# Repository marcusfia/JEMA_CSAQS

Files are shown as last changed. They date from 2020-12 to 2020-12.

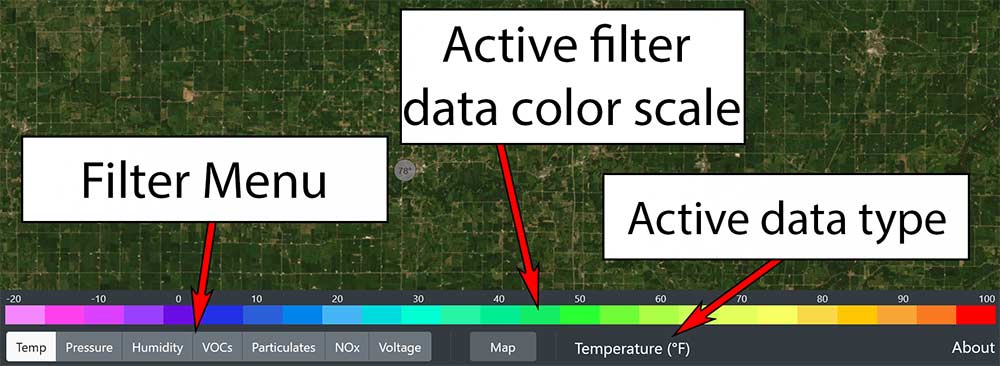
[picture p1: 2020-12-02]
wiki/images/desktop_menu2.jpg

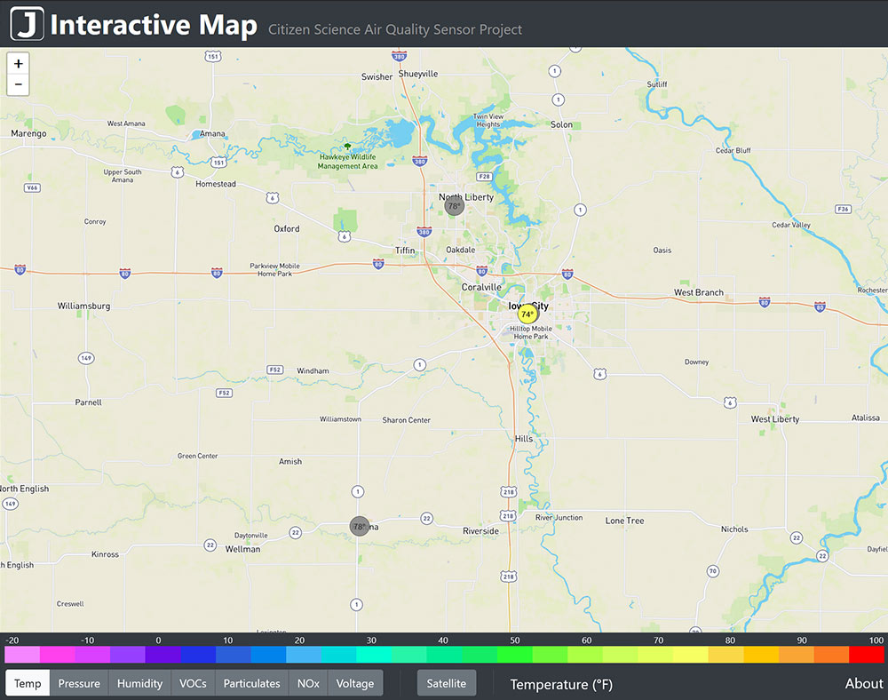
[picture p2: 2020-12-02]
wiki/images/fullmap.jpg

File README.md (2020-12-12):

# **JEMA SD Project - Citizen Science Air Quality Sensor**
Sponsered by Dr. Jun Wang and the University of Iowa ARROMA Lab

This repository contains all source code used for the project.

If you would like to know more about the project software/hardware or access user guides, please visit the project wiki:

## [Project Wiki](https://github.com/marcusfia/JEMA_CSAQS/wiki)

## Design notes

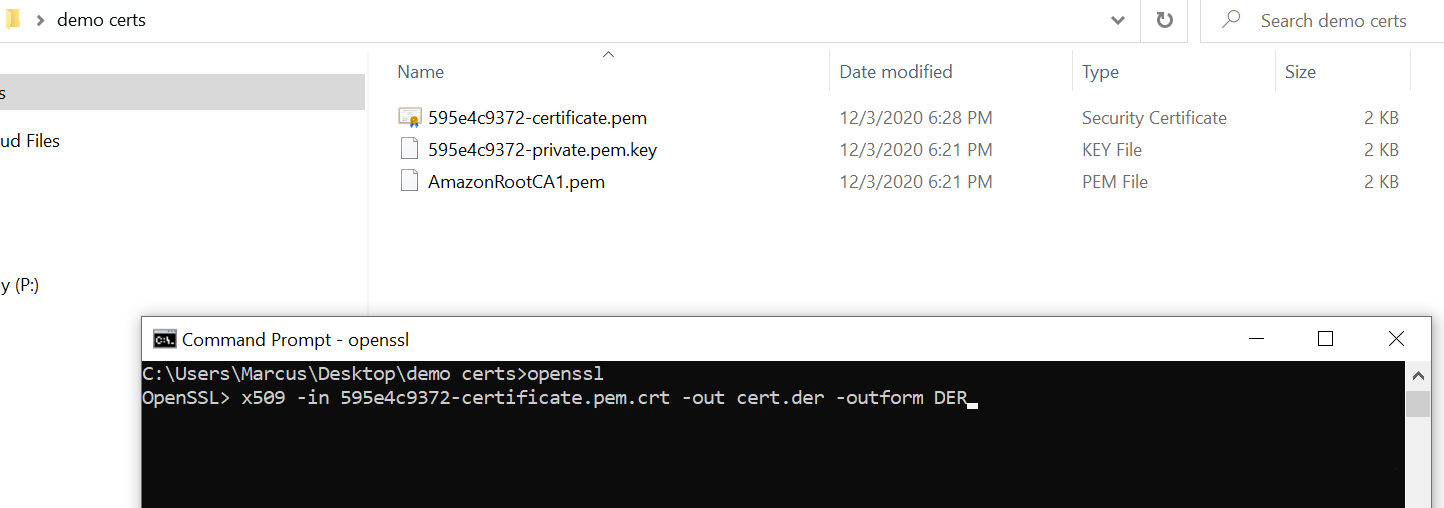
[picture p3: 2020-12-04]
wiki/images/cert_4.png

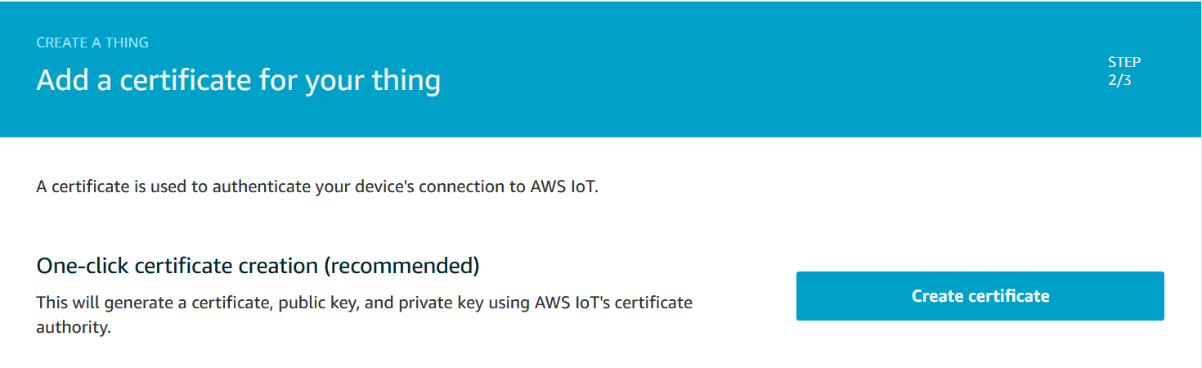
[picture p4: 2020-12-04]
wiki/images/cert_1.png

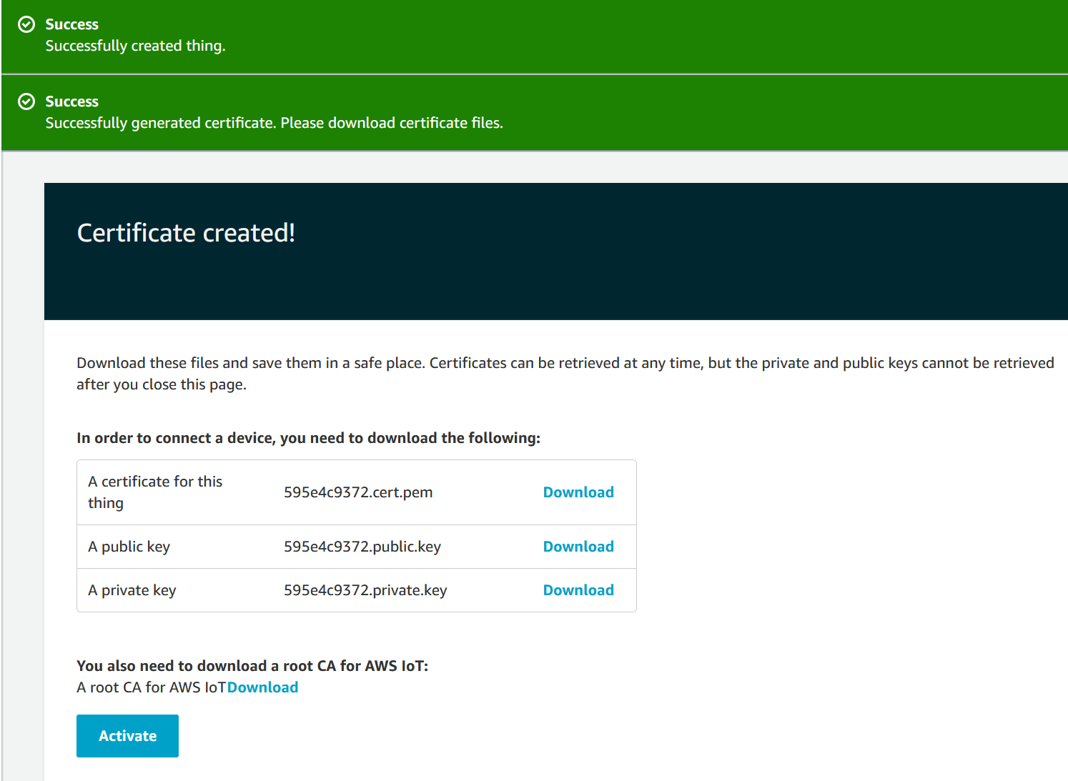
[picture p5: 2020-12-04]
wiki/images/cert_2.png

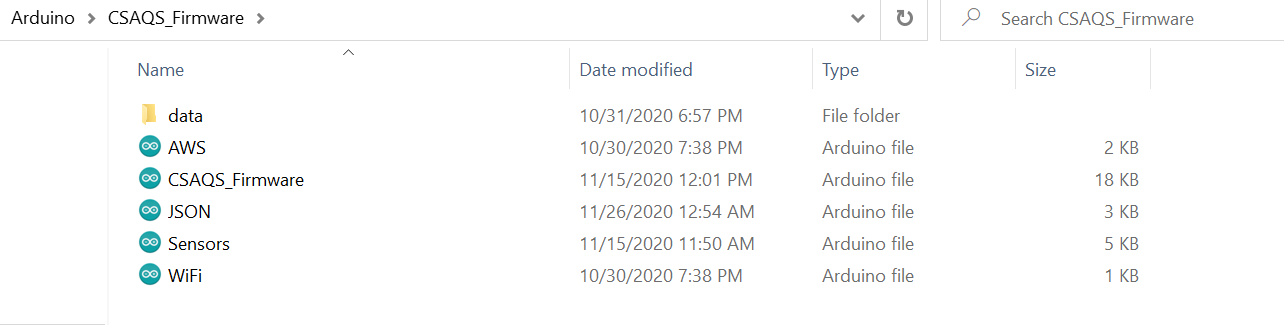
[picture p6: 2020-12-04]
wiki/images/cert_6.png

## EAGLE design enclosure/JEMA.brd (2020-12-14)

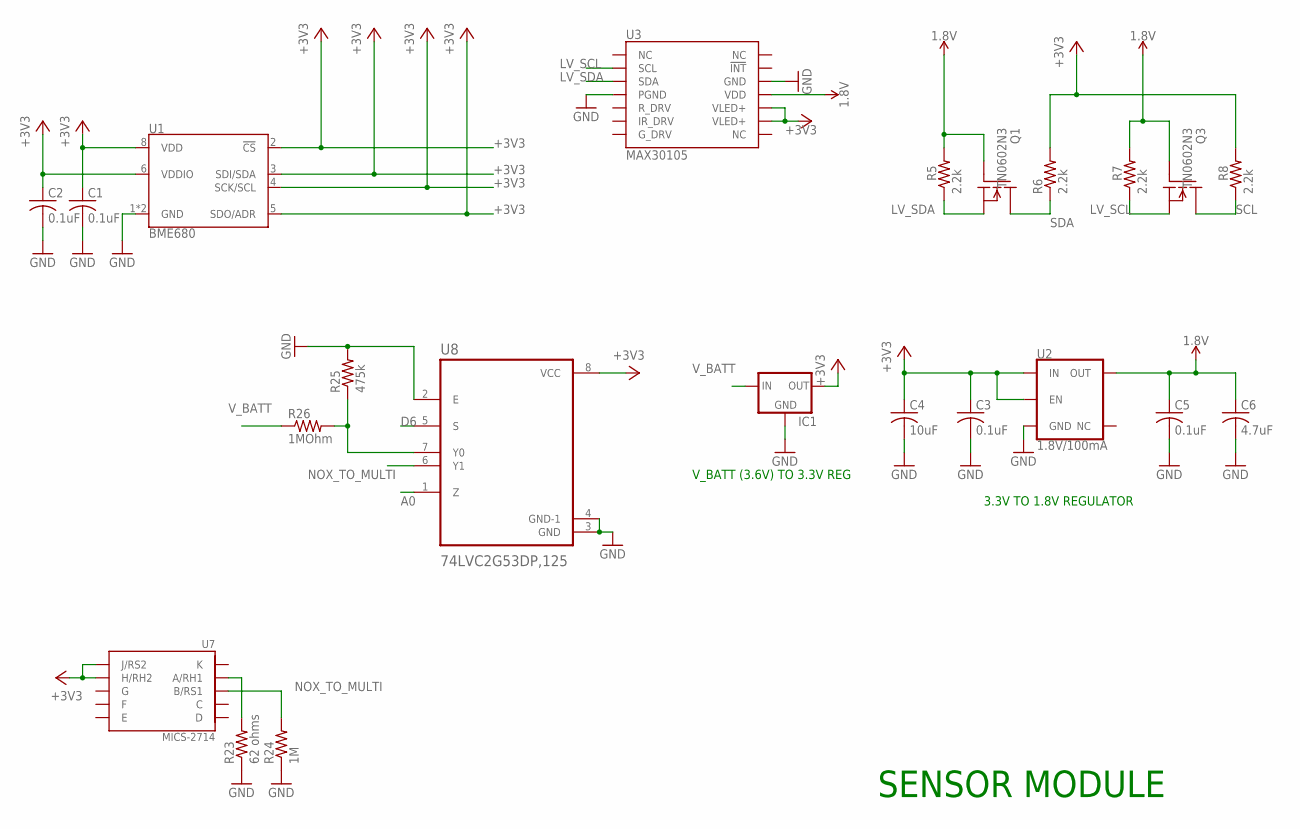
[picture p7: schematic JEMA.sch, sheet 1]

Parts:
C1, C2, C3, C5: 0.1uF; C0805
C4: 10uF; C0805
C6: 4.7uF; C0805
IC1: MCP1700TRI; TO92
Q1, Q3: TN0602N3; TO-92
R5, R6, R7, R8: 2.2k; R0805
R23: 62 ohms; M0805
R24: 1M; M0805
R25: 475k; M0805
R26: 1MOhm; M0805
U1: BME680; LGA3.0X3.0
U2: 1.8V/100mA; SC70
U3: MAX30105; OLGA-14
U7: MICS-2714; MICS-SMD10
U8: 74LVC2G53DP,125; SOP65P490X110-8N

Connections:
1.8V: C5.1, C6.1, Q1.2 (G), Q3.2 (G), R5.2, R7.2, U2.5 (OUT), U3.11 (VDD)
+3V3: C1.1, C2.1, C3.1, C4.1, IC1.3 (OUT), R6.2, R8.2, U1.2 (!CS), U1.3 (SDI/SDA), U1.4 (SCK/SCL), U1.5 (SDO/ADR), U1.6 (VDDIO), U1.8 (VDD), U2.1 (IN), U2.3 (EN), U3.9 (VLED+), U3.10 (VLED+), U7.H (H/RH2), U7.J (J/RS2), U8.8 (VCC); also elsewhere on the board
A0: U8.1 (Z); also elsewhere on the board
D6: U8.5 (S); also elsewhere on the board
GND: C1.2, C2.2, C3.2, C4.2, C5.2, C6.2, IC1.1 (GND), R23.1, R24.1, R25.2, U1.1 (GND), U1.7 (GND), U2.2 (GND), U3.4 (PGND), U3.12 (GND), U8.2 (E), U8.3 (GND), U8.4 (GND-1); also elsewhere on the board
LV_SCL: Q3.1 (S), R7.1, U3.2 (SCL)
LV_SDA: Q1.1 (S), R5.1, U3.3 (SDA)
unnamed: R25.1, R26.2, U8.7 (Y0)
unnamed: R23.2, U7.A (A/RH1)
NOX_TO_MULTI: R24.2, U7.B (B/RS1), U8.6 (Y1)
SCL: Q3.3 (D), R8.1; also elsewhere on the board
SDA: Q1.3 (D), R6.1; also elsewhere on the board
V_BATT: IC1.2 (IN), R26.1; also elsewhere on the board

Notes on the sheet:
V_BATT (3.6V) TO 3.3V REG
3.3V TO 1.8V REGULATOR
SENSOR MODULE

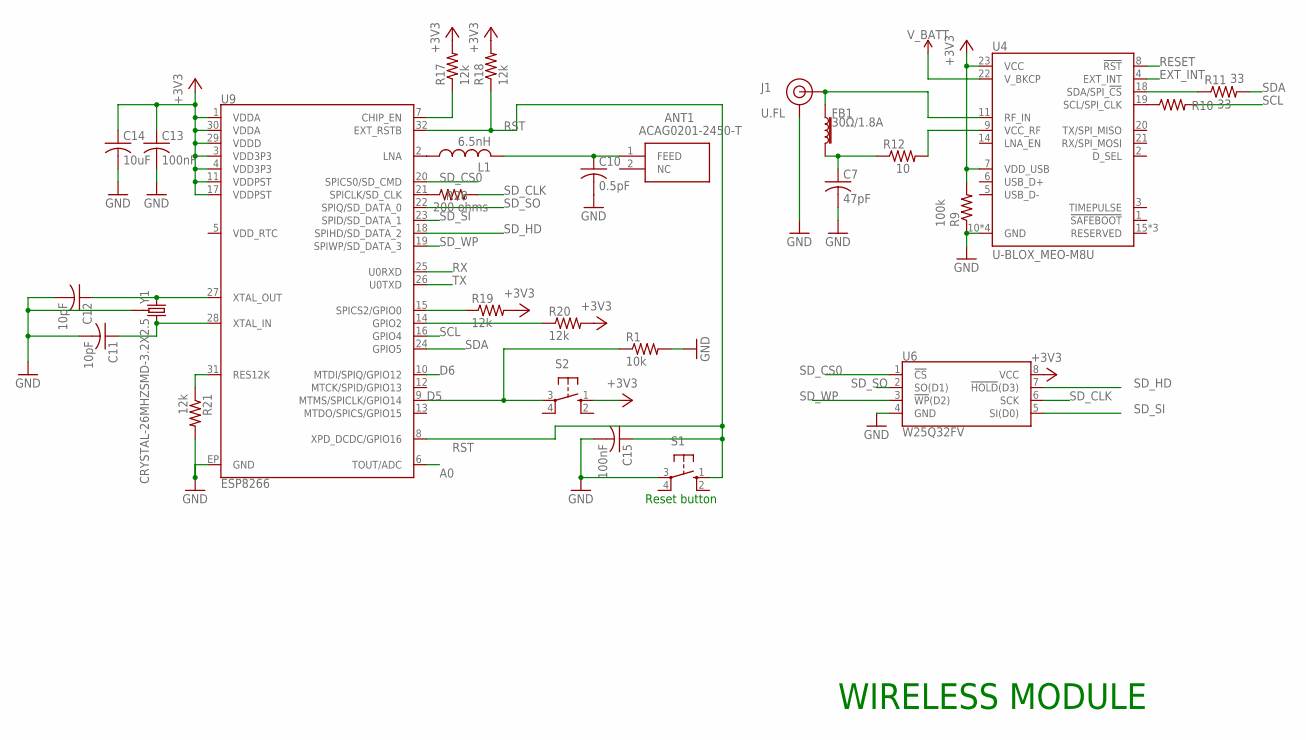
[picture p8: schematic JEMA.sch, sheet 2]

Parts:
ANT1: ACAG0201-2450-T; ANTC2012X70N
C7: 47pF; C0805
C10: 0.5pF; C0805
C11, C12: 10pF; C0805
C13, C15: 100nF; C0805
C14: 10uF; C0805
FB1: 30Ω/1.8A; 0603
J1: U.FL
L1: 6.5nH; L3225M
R1: 10k; R0805
R9: 100k; R0805
R10, R11: 33; R0805
R12: 10; R0805
R17, R18, R19, R20, R21: 12k; M0805
R28: 200 ohms; R0805
S1, S2: 10-XX; B3F-10XX
U4: U-BLOX_MEO-M8U; NEO-M9N/M8T/M8U
U6: W25Q32FV; SOIC-8
U9: ESP8266; QFN32-5X5MM
Y1: CRYSTAL-26MHZSMD-3.2X2.5; CRYSTAL-SMD-3.2X2.5MM

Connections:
+3V3: C13.1, C14.1, R9.2, R17.2, R18.2, R19.2, R20.2, S2.1 (S), U4.7 (VDD_USB), U4.23 (VCC), U6.8 (VCC), U9.1 (VDDA), U9.3 (VDD3P3), U9.4 (VDD3P3), U9.11 (VDDPST), U9.17 (VDDPST), U9.29 (VDDD), U9.30 (VDDA); also elsewhere on the board
A0: U9.6 (TOUT/ADC); also elsewhere on the board
D5: R1.1, S2.3, U9.9 (MTMS/SPICLK/GPIO14)
D6: U9.10 (MTDI/SPIQ/GPIO12); also elsewhere on the board
EXT_INT: U4.4 (EXT_INT)
GND: C7.2, C10.2, C11.2, C12.2, C13.2, C14.2, C15.2, J1.1 (GND), J1.2 (GND), R1.2, R9.1, R21.2, S1.3, U4.10 (GND), U4.12 (GND), U4.13 (GND), U4.24 (GND), U6.4 (GND), U9.EP (GND), Y1.2 (GND), Y1.4 (GND); also elsewhere on the board
unnamed: R10.1, U4.19 (SCL/SPI_CLK)
unnamed: R11.1, U4.18 (SDA/SPI_!CS!)
unnamed: C7.1, FB1.2, R12.1
unnamed: R12.2, U4.9 (VCC_RF)
unnamed: R17.1, U9.7 (CHIP_EN)
unnamed: L1.1, U9.2 (LNA)
unnamed: ANT1.1 (FEED), C10.1, L1.2
unnamed: R19.1, U9.15 (SPICS2/GPIO0)
unnamed: R20.1, U9.14 (GPIO2)
unnamed: R21.1, U9.31 (RES12K)
unnamed: C12.1, U9.27 (XTAL_OUT), Y1.1
unnamed: C11.1, U9.28 (XTAL_IN), Y1.3 (2)
unnamed: FB1.1, J1.FEED (SIGNAL), U4.11 (RF_IN)
unnamed: R28.1, U9.21 (SPICLK/SD_CLK)
RESET: U4.8 (!RST)
RST: C15.1, R18.1, S1.1 (S), U9.8 (XPD_DCDC/GPIO16), U9.32 (EXT_RSTB)
RX: U9.25 (U0RXD)
SCL: R10.2, U9.16 (GPIO4); also elsewhere on the board
SDA: R11.2, U9.24 (GPIO5); also elsewhere on the board
SD_CLK: R28.2, U6.6 (SCK)
SD_CS0: U6.1 (!CS!), U9.20 (SPICS0/SD_CMD)
SD_HD: U6.7 (!HOLD!(D3)), U9.18 (SPIHD/SD_DATA_2)
SD_SI: U6.5 (SI(D0)), U9.23 (SPID/SD_DATA_1)
SD_SO: U6.2 (SO(D1)), U9.22 (SPIQ/SD_DATA_0)
SD_WP: U6.3 (!WP!(D2)), U9.19 (SPIWP/SD_DATA_3)
TX: U9.26 (U0TXD)
V_BATT: U4.22 (V_BKCP); also elsewhere on the board

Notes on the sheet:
Reset button
WIRELESS MODULE

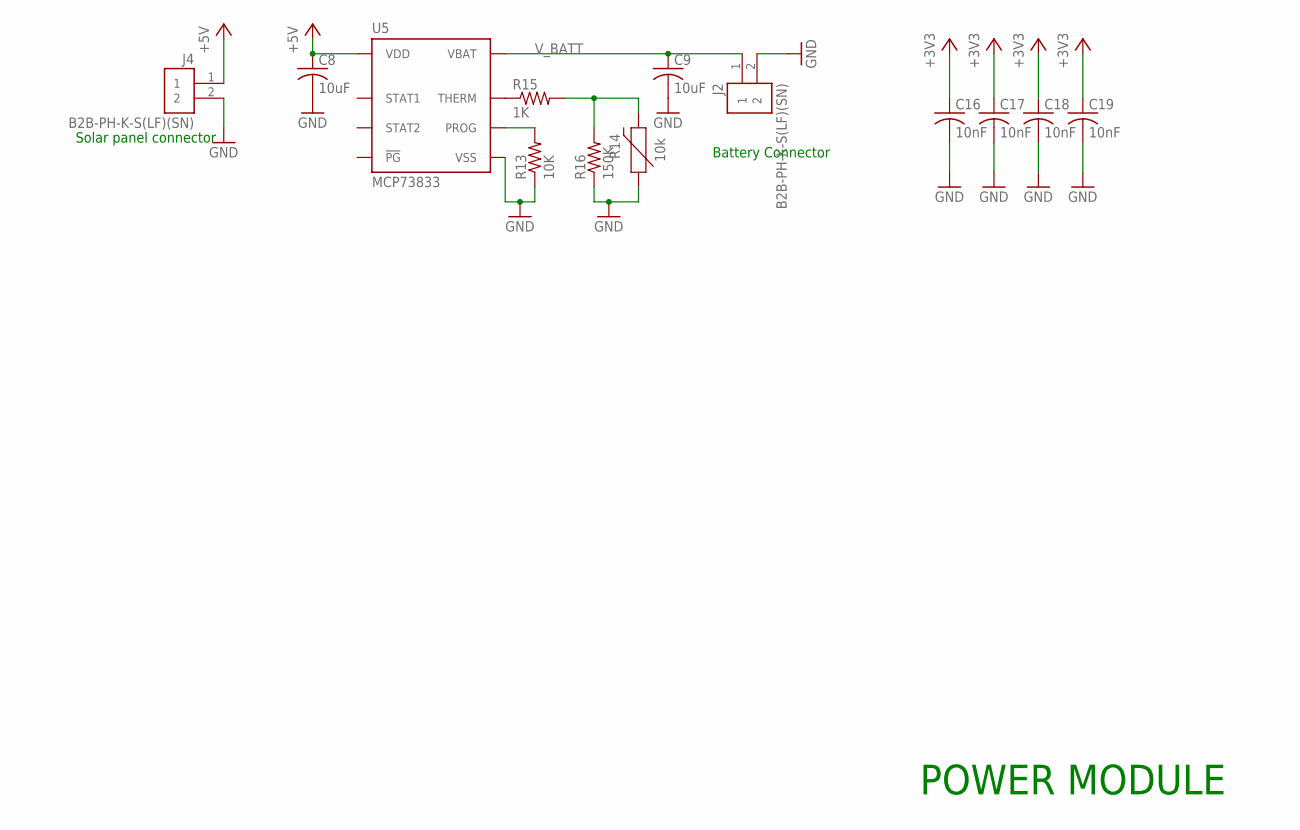
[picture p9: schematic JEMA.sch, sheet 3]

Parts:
C8, C9: 10uF; C0805
C16, C17, C18, C19: 10nF; C0805
J2, J4: B2B-PH-K-S(LF)(SN); JST_B2B-PH-K-S(LF)(SN)
R13: 10K; R0805
R14: 10k; 0603
R15: 1K; R0805
R16: 150K; R0805
U5: MCP73833; DFN-10

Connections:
+3V3: C16.1, C17.1, C18.1, C19.1; also elsewhere on the board
+5V: C8.1, J4.1, U5.P$1 (VDD), U5.P$2 (VDD)
GND: C8.2, C9.2, C16.2, C17.2, C18.2, C19.2, J2.2, J4.2, R13.1, R14.1, R16.1, U5.P$5 (VSS), U5.P$11 (VSS); also elsewhere on the board
unnamed: R13.2, U5.P$6 (PROG)
unnamed: R15.1, U5.P$8 (THERM)
unnamed: R14.2, R15.2, R16.2
V_BATT: C9.1, J2.1, U5.P$9 (VBAT), U5.P$10 (VBAT); also elsewhere on the board

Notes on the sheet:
POWER MODULE
Battery Connector
Solar panel connector

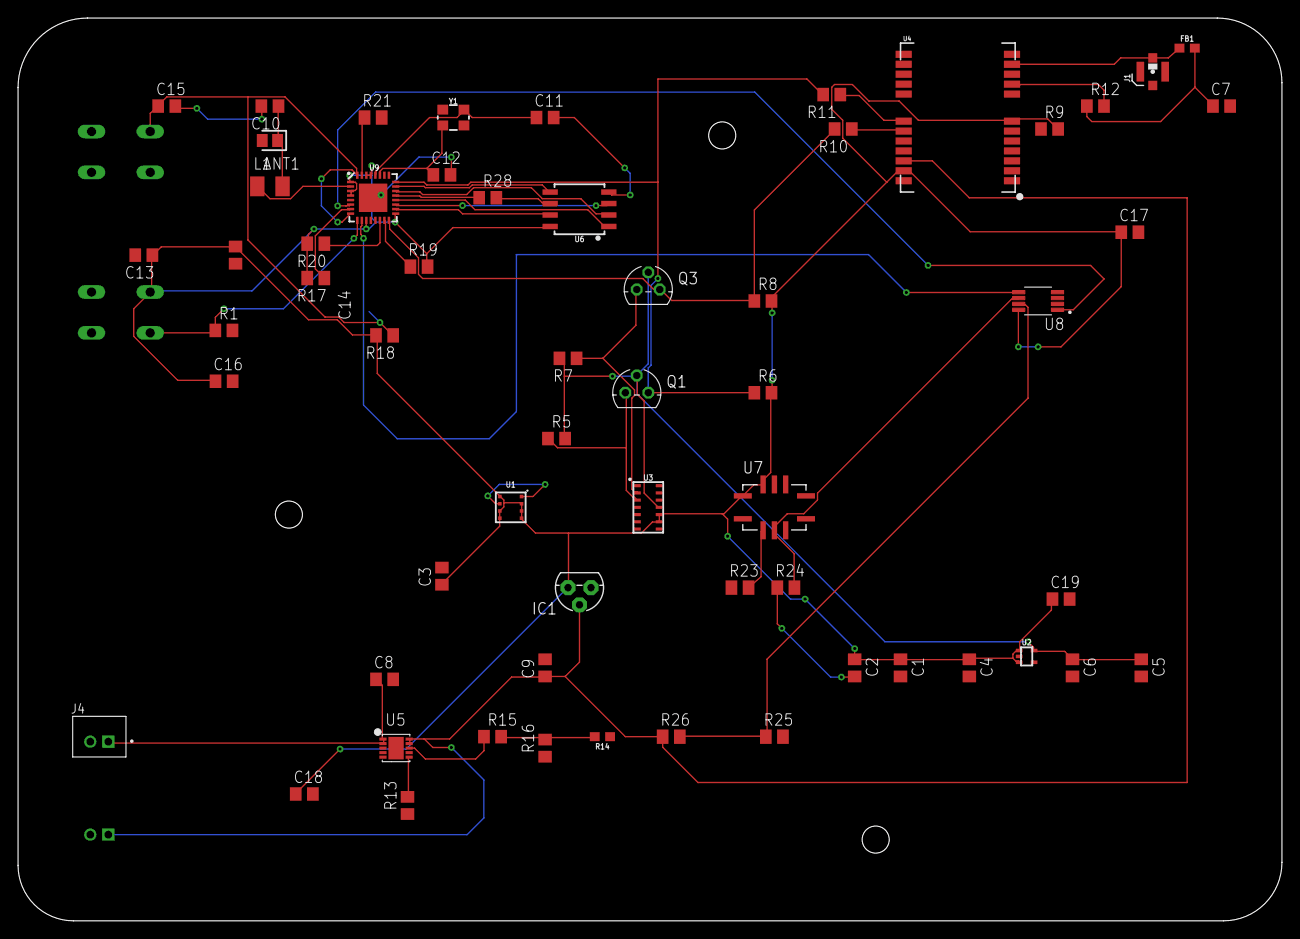
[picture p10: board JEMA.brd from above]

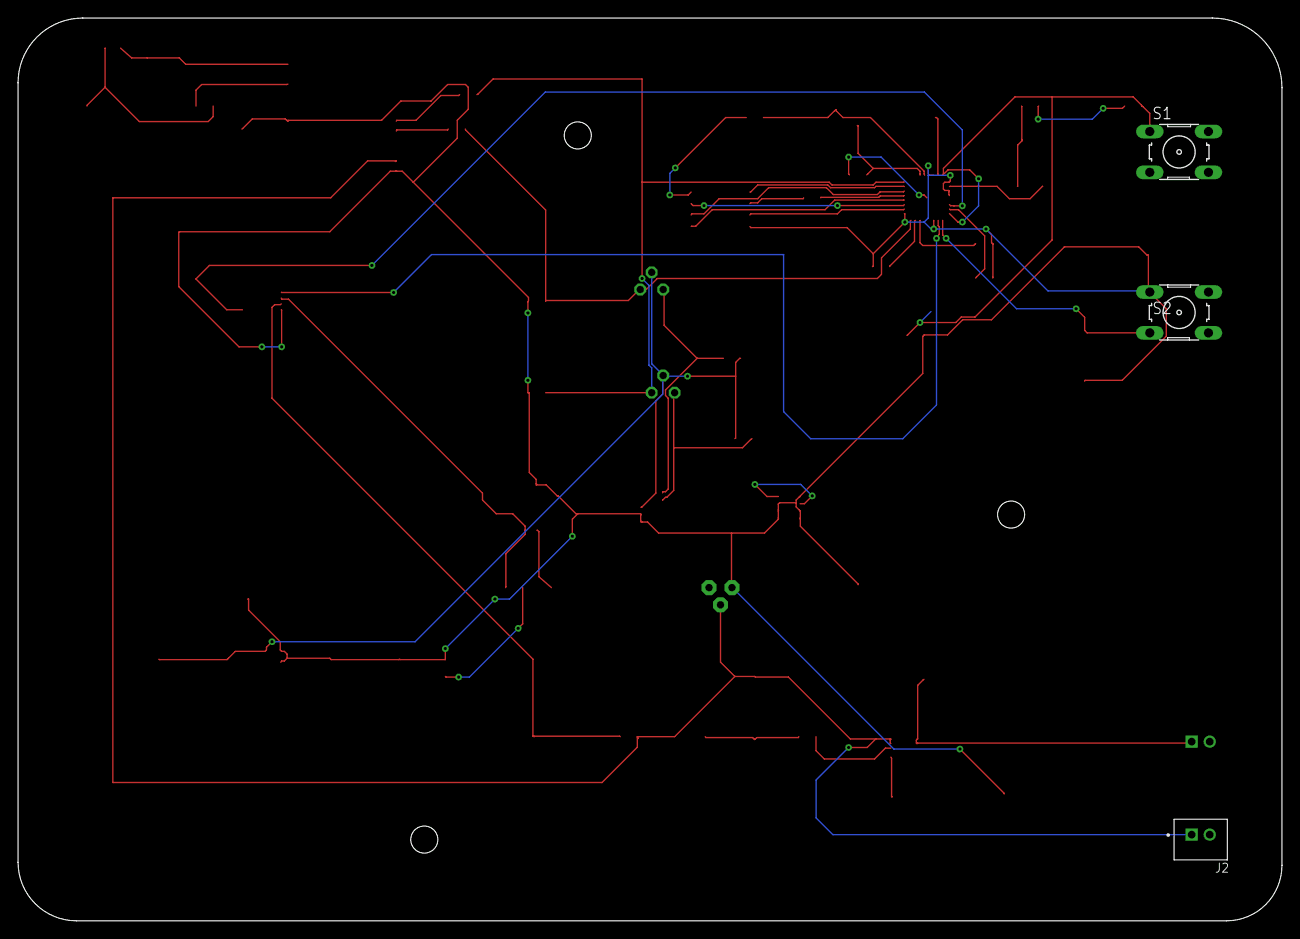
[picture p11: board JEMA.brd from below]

Board: 2 copper layers, 140.0 x 100.0 mm, 63 parts (3 on the bottom side), 39 nets.

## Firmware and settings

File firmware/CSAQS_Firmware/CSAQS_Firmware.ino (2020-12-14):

//////////////////////////////////////////////////////////////////////////////////////////////////////////////////////////////////////
//                             Citizen Science Air Quality Sensor - Device Firmware  (v0.1)
//
//                                                       by
//
//                                                   JEMA Designs
//
//
//                               University of Iowa - Electrical and Computer Engineering
//                                         Senior Design Project - Fall 2020
// 
//
//
//
//                                               in conjunction with -
//
//
//
//
//
//
//                                       Dr. Jun Wang & ARROMA Lab (arroma.uiowa.edu)
//
//   NOTES  ----------------------------------------------------------------------------------------------------------------------
//   9/12/2020 (AW)  - This is a sample note. Start each note with the date, and your initials in paretheses.  Do no remove notes
//   , instead update with a new note, stating that the previous issue is now resolved or changed (reference to the date to make it
//   simple to find what matches to what.  Use multiple lines if needed for a given note, like this one.
//   9/33/2020 (AW)  - This would be the next note......
//   9/04/2020 (AW)  - Added code to read push button to be used for forcing device into Access Point mode. Push button will be a pull
//   -down resistor in order to consume the least amount of power.
//   10/20/2020 (AW) - Contributions by Jarrett for polling of sensors and reading of analog inputs
//   10/20/2020 (AW) - Merged firmware code with Marcus's wifi transmission firmware. Includes MQTT setup, AWS connection & WiFi connection
//   10/21/2020 (AW) - Added code to read & translate NOx sensor
//   10/21/2020 (AW) - Built out deep sleep mode and alpha device firmware --NOTE Deep Sleep not currently active,falls through to main loop
//   10/23/2020 (AW) - Major re-organization of code; usage of Arduino file tabs to separate out code and make more legible
//   10/23/2020 (AW) - Added new debug flag - DEBUG_OUT, for turning on and off the Serial data.  Can be used during normal or debug modes
//   10/23/2020 (AW) - Added enumerations for checking the power supply values, added logic points for dealing with power supply
//   10/24/2020 (AW) - Added changes Marcus made to JSON payload, added Jarrett's SIV code, added Marcus's device ID code
//   10/29/2020 (JH) - Added WifiManager and made it so AP can get a wifi and be resest with a buttonPressed Commented out because it suppresses
//   - the Serial output
//   10/30/2020 (MF) - Updated JSON to not prepend mac address to clientID. This was causing conflicts in API Gateway.
//   10/31/2020 (MF) - Updated TTL in JSON to 30 from 600 to decrease burden on DB and updated delays for loading certs from 1s to 100ms.
//   11/01/2020 (AW) - Fixed battery level calculation.
//   11/09/2020 (AW) - Implemented sleep mode for GPS, cleaned up & re-organized code
//   11/12/2020 (AW) - Implemented sampling protocol for analog input - uses an averaging method, variable re-naming
//   11/22/2020 (AW) - Added check against the fix statue of the GPS.  If no good GPS, wait 5 seconds, try again. Do this up to 10 times, then move on.
//   11/22/2020 (AW) - Added else checks to power supply if block to avoid unneeded checks
//   11/23/2020 (AW) - Adjusted power supply value enumerations based on battery life testing

//////////////////////////////////////////////////////////////////////////////////////////////////////////////////////////////////////
// DEBUG FLAGS    
boolean DEBUG_MODE = false;            // SET DEBUG MODE to TRUE to disable WIFI/AWS/MQTT and Payload Transmit

boolean DEBUG_OUT = true;             //Turns on and off the serial output messages

boolean SENSOR_CAPTURE_MODE = false;  //Uses AWS transmission, but different sampling frequencies and no enabled sleep mode

//////////////////////////////////////////////////////////////////////////////////////////////////////////////////////////////////////
//  Include Headers

#include "FS.h"
#include <ESP8266WiFi.h>
#include <PubSubClient.h>
#include <NTPClient.h>
#include <WiFiUdp.h>
#include <Wire.h>
#include <EEPROM.h>                             //EEPROM storage in Flash used for UBLOX-GPS

#include <WiFiManager.h>                        //https://github.com/tzapu/WiFiManager WiFi Configuration Magic
#include "Zanshin_BME680.h"                     //BME680 by Zanshin

#include "SparkFun_Ublox_Arduino_Library.h"     //u-blox NEO-M8U

#include "heartRate.h"                          //MAX 30105
#include "spo2_algorithm.h"                     //MAX 30105
#include "MAX30105.h"                           //MAX 30105

//////////////////////////////////////////////////////////////////////////////////////////////////////////////////////////////////////
//  Enumerations
enum PowerSupplyState 
{
  PWR_UNKNOWN  = 0,
  BATT_AT_DEAD = 1,
  BATT_AT_10   = 2,
  BATT_AT_50   = 3,
  BATT_AT_75   = 4,
  BATT_AT_MAX  = 5,
  SOLAR_PWR    = 6
};

enum PowerSupplyValues //Correlate the voltage x 100 (e.g. 360 = 3.60 volts x 100)
{
  BATTERY_DEAD = 355,
  BATTERY_10   = 358,
  BATTERY_20   = 366,
  BATTERY_50   = 390,
  BATTERY_75   = 410,
  BATTERY_MAX  = 430
};

enum DeepSleepDuration
{
  DUR_1HR = 3600,
  DUR_5MIN = 300,
  DUR_10MIN = 600,
  DUR_10SEC = 10,
  DUR_30SEC = 30
};
//////////////////////////////////////////////////////////////////////////////////////////////////////////////////////////////////////
//  Hardware Defines

#define UART_SPD    115200         //Serial communication speed setting

// Wemos board pin definitions to ESP8266 definitions
#define D0          16         //Used for deep sleep functions - DO NOT USE
#define D1          5          //SCL for I2C
#define D2          4          //SDA for I2C
#define D3          0          //Used for programming chip
#define D4          2          //Used for programming chip
#define D5          14         //Used for push button
#define D6          12         //Used for multiplexer select
#define D7          13
#define D8          15

//Device specific pin/logic defines
#define MUX_SELECT   12        //Multiplexer Select pin
#define SCL          5         //SCL pin
#define SDA          4         //SDA pin
#define PUSH_BUTTON  14        //Push button input pin
#define PWR_SUPPLY   0         //Logic level for MUX_SELECT to read power supply input from analog read
#define NOX_SENSOR   1         //Logic level for MUX_SELECT to read NOX sensor from analog read

//////////////////////////////////////////////////////////////////////////////////////////////////////////////////////////////////////
//  Objects and Variable

// AWS Credentials
const char* AWS_ENDPOINT  = "a3rqtvxgwfds5w-ats.iot.us-west-2.amazonaws.com";
char* AWS_IOT_CORE_CLIENT_ID = "trappist";
char* AWS_IOT_CORE_PUBLISH_TOPIC = "trappist/pub"; // AWS topic to publish to
const int MQTT_PAYLOAD_SIZE = 512;                 // Max size for buffer for payload
String payload;                                    // Stores the payload information
String db_device_ID;                               // Creates unique ID for queries
char msg[MQTT_PAYLOAD_SIZE];                       // stores msg to publish


//for receving messages IF the device is subscribed to something (not applicable currently)
void callback(char* topic, byte* payload, unsigned int length)
{
  Serial.print("Message arrived [");
  Serial.print(topic);
  Serial.print("] ");
  for (int i = 0; i < length; i++) 
  {
    Serial.print((char)payload[i]);
  }
}


// Instance Objects
WiFiClientSecure espClient;
PubSubClient client(AWS_ENDPOINT, 8883, callback, espClient); 
WiFiUDP ntpUDP;
NTPClient timeClient(ntpUDP, "pool.ntp.org");
BME680_Class BME680;        //BME60 I2C address = 0x77
MAX30105 particleSensor;    //MAX30105 I2C address = 0x57
SFE_UBLOX_GPS ubloxGPSObj;  //GPS I2C address = 0x42
WiFiManager wifiManager;

//BME680 variables
static int32_t temp;
static int32_t humidity;
static int32_t pressure;
static int32_t gas;
String tempStr;
String humidityStr;
String pressureStr;
String gasStr;

//Sensor enabled check declarations
bool gpsEnabled      = false;
bool bme680Enabled   = false;
bool max30105Enabled = false;

//Analog read & power supply variables
float voltage_divider_scalar = 19.936;      // power supply divison coeffecient 
float NOx_voltage_divider_scalar = 3.21056; //coefficient for NOx sensor reading
float ADC_resolution = 1024;                // 10 bit ADC
int read_A0;                                // Pin A0 on ESP8266 used for analog read of power
int currentPowerState;                      // Stores enumeration of current status of power supply
float vcc;
float noxSensorRead;

//MAX30105 variables
String red;  
String green;
String IR;

//u-blox variables
String latitude;
String longitude;
String altitude;
byte SIV;

//Deep Sleep Duration (in seconds)
static int32_t deepSleepDuration;

//////////////////////////////////////////////////////////////////////////////////////////////////////////////////////////////////////
// Setup

void setup()
{
  if(DEBUG_OUT)  //If using our serial output, set it up
  {
    Serial.begin(UART_SPD);
    Serial.setDebugOutput(true);
    delay(1000);
  }
  deepSleepDuration = DUR_5MIN;     //Default sampling rate is set here
  
  // setup pins and multiplexer
  pinMode(MUX_SELECT, OUTPUT);
  pinMode(PUSH_BUTTON, INPUT);
  digitalWrite(MUX_SELECT, PWR_SUPPLY);
  Wire.begin();

  db_device_ID = transmit_createClientID();
  CheckPowerSupply();               //Checks reading from power supply, determines if we should move on to rest of program or deal with low supply power
  CheckForPushButtonPresses();      //Check to see if we are holding the button at startup

  if(DEBUG_MODE)  //If in debug mode, set duration to 10 seconds, will ues delay loop
  {
    deepSleepDuration = DUR_10SEC;
    if(DEBUG_OUT) Serial.println("*DEBUG_MODE ACTIVE* Not attempting to connect to WiFi");
  }
  else
  {
    SetupWifiConnection();
  }

  delay(1000);
  
  if (!SPIFFS.begin())
  {
    if(DEBUG_OUT) Serial.println("Failed to mount file system"); 
    return;
  }

  delay(1000);
    
  InitializeBME680();
  InitialzieMAX30105();
  InitializeNEOM8U();

  /* START Time Client   ***************************/
  timeClient.begin();
  
  LoadAWSCertificate();

  //    New 'main loop'. Executes once each start up.  Deep sleep takes device back to reset, so only setup loop is run if we
  // are using deepsleep (debug_mode == false). If not, then proceeds to loop() where it uses a delay rather than deepsleep.  This 
  // delay will consume power, whereas deepsleep does not. In loop(), debug_mode == true, and some functionality is turned off during
  // debug mode. Review proceeding code to determine what functionality is turned off.

  //Main loop
  int counter = 0;
  if(gpsEnabled)
  {
      while(ubloxGPSObj.getFixType() < 2 && counter < 10) //If we don't have good fix, wait a bit, check again. Don't do this more than 10 times
      {
        delay(5000); //give it some time to try again
        counter++;
      }
  }

  ConnectToMQTT();
  PollSensors();
  BuildJSONPayload();
  SendJSONPayload();
  // End of Main loop

  
  if(!DEBUG_MODE) EnterDeepSleepMode(deepSleepDuration); //If we are in normal operation, go to sleep, else go to loop()

  if(SENSOR_CAPTURE_MODE)  //If using our serial output, set it up
  {
    Serial.begin(UART_SPD);
    Serial.setDebugOutput(true);
    delay(1000);
    Serial.println("NOx,VOC");
  }
  
}


//////////////////////////////////////////////////////////////////////////////////////////////////////////////////////////////////////
// Main Loop
//This is only entered if the device is set to debug mode (DEBUG_MODE = true);
void loop()
{
    ConnectToMQTT();
    PollSensors();
    BuildJSONPayload();
    SendJSONPayload();
    if(SENSOR_CAPTURE_MODE)
    {
      Serial.println(String(noxSensorRead) + "," + gasStr);
      delay(10*1000);  //ten second delay
    }
    else
    {
      delay(deepSleepDuration * 1000); 
    }
    
}

//////////////////////////////////////////////////////////////////////////////////////////////////////////////////////////////////////
// Methods and Functions
// Groups of functions are also split out into the tabs in the Arduino IDE

//This function will contain our logic for determing what to do when based on our current estimates of power left in battery
void CheckPowerSupply()
{
  currentPowerState = PWR_UNKNOWN;
  int voltageReading = SampleAnalogInput();
  int convertedVoltageReading =(int)(((float)voltageReading * (voltage_divider_scalar / ADC_resolution)) * 100); //converts from x.xx to xxx

  if(convertedVoltageReading > BATTERY_MAX)                                                   currentPowerState = SOLAR_PWR;
  else if(convertedVoltageReading <= BATTERY_MAX && convertedVoltageReading >= (BATTERY_MAX - 10)) currentPowerState = BATT_AT_MAX;
  else if(convertedVoltageReading < (BATTERY_MAX - 10) && convertedVoltageReading >= BATTERY_75)   currentPowerState = BATT_AT_75;
  else if(convertedVoltageReading < BATTERY_75 && convertedVoltageReading >= BATTERY_20)           currentPowerState = BATT_AT_50;
  else if(convertedVoltageReading < BATTERY_20 && convertedVoltageReading >= BATTERY_10)           currentPowerState = BATT_AT_10;
  else if(convertedVoltageReading < BATTERY_10 && convertedVoltageReading >= BATTERY_DEAD)         currentPowerState = BATT_AT_DEAD;

  switch(currentPowerState)  //What to do based on our current power situation
  {
    case SOLAR_PWR:
    if(DEBUG_OUT) Serial.println("CheckPowerSupply status = SOLAR_PWR");
    break;
    case BATT_AT_MAX:
    if(DEBUG_OUT) Serial.println("CheckPowerSupply status = BATT_AT_MAX");
    break;
    case BATT_AT_75:
    if(DEBUG_OUT) Serial.println("CheckPowerSupply status = BATT_AT_75");
    break;
    case BATT_AT_50:
    if(DEBUG_OUT) Serial.println("CheckPowerSupply status = BATT_AT_50");
    break;    
    case BATT_AT_10:
    {
      if(DEBUG_OUT) Serial.println("CheckPowerSupply status = BATT_AT_10, entering deep sleep");
      //EnterDeepSleepMode(deepSleepDuration);
    }
    break;
    case BATT_AT_DEAD:
    {
      if(DEBUG_OUT) Serial.println("CheckPowerSupply status = BATT_AT_DEAD, entering deep sleep");
      //EnterDeepSleepMode(deepSleepDuration);
    }
    break;
    default:   //PWR_UNKNOWN or non-handled #s
    if(DEBUG_OUT) Serial.println("CheckPowerSupply status = PWR_KNOWNN");
    break;
  }
}

void CheckForPushButtonPresses()
{
  int numberOfPresses = 0;
  bool pressed = digitalRead(PUSH_BUTTON);
  numberOfPresses++;
  while(pressed)
  {
    numberOfPresses++;
    if(numberOfPresses > 20)             //20 is an abritrary number.  Based on the delay below and the approx. amount of time we want to hold the button. Setting a low delay # means it leaves this while loop faster
    {
      //Go to AP mode start
      BeginAPMode();
      numberOfPresses = 0;
    }
    pressed = digitalRead(PUSH_BUTTON);
    delay(100);                         //100 is a small duration.  If we let go, it should move on from this function fast.  
  }
}

void BeginAPMode()
{
  wifiManager.resetSettings();
  wifiManager.autoConnect("Jema");
}

//MQTT reconnection attempts to reconnect every 5 seconds until it makes a connection
void reconnect() 
{
  while (!client.connected()) 
  {
    if(DEBUG_OUT) Serial.print("Attempting MQTT connection...");
    // Attempt to connect
    if (client.connect(AWS_IOT_CORE_CLIENT_ID)) 
    {
      if(DEBUG_OUT) Serial.println("connected");
    } 
    else 
    {
      if(DEBUG_OUT) 
      {
        Serial.print("failed, rc=");
        Serial.print(client.state());
        Serial.println(" try again in 5 seconds");
      
        char buf[256];
        espClient.getLastSSLError(buf,256);
        Serial.print("WiFiClientSecure SSL error: ");
        Serial.println(buf);
      }
      
      // Wait 5 seconds before retrying
      delay(5000);
    }
  }
}

//Checks if we are connected to the MQTT server, attempts to establish a connection if not.  
void ConnectToMQTT()
{
  if(!DEBUG_MODE)
  {
      if (!client.connected()) 
      {
        if(DEBUG_OUT) Serial.println("reconnect()");
        reconnect();
      }
      client.loop();
  }
  else if(DEBUG_OUT) Serial.println("*DEBUG_MODE ACTIVE* No MQTT connection Attempted");
}

int SampleAnalogInput()
{
  int analogInputReading = 0;
  for(int i = 0; i < 10; i++)
  {
    analogInputReading += analogRead(A0);
  }
  return analogInputReading /= 10;  //sample analog input 10 times and average the result
}

//One method call to poll all the current sensors
void PollSensors()
{
  client.setBufferSize(MQTT_PAYLOAD_SIZE);  //Ensure we have enough space in the buffer for all our data
  PollPowerSupply();
  PollNOxSensor();
  PollBME680();
  PollMAX30105();
  PollNEOM8U();
}

//Send the JSON payload. Just call BuildJSONPayload first or else it will be an empty payload
void SendJSONPayload()
{
   payload.toCharArray(msg, MQTT_PAYLOAD_SIZE);
   if(!DEBUG_MODE)
   {
     // publish msg to AWS topic:
     int payLoadLength = payload.length();
     int result = client.publish(AWS_IOT_CORE_PUBLISH_TOPIC, msg);
     if(DEBUG_OUT) Serial.println("Client id = " + db_device_ID + ", Payload size = " + String(payLoadLength) + ",client.publish = " + String(result) + "\r\n");
   }
   else if(DEBUG_OUT) Serial.println("*DEBUG_MODE ACTIVE* No Payload Sent!\r\n");
   payload = "";                  //empty String payload buffer
   memset(msg, 0, sizeof(msg));   //empty msg buffer
}

// Turns off all devices to save power, sets deepsleep on ESP8266 for duration seconds
void EnterDeepSleepMode(uint32_t duration)
{
  //put MAX to sleep
  particleSensor.shutDown();
  //Put NEO M8U to sleep
  bool gpsConfirmSleep = ubloxGPSObj.powerOff((duration * 900), 100);  //Duration of sleep in ms (zero for infinite), maximum timeout to wait for resposne from GPS module 
  //Put anything else to sleep
  if(DEBUG_OUT) Serial.println("u-blox powerOff response = " + String(gpsConfirmSleep));
  if(DEBUG_OUT) Serial.println("Entering sleep mode.... ");
  ESP.deepSleep(duration * 1000000);  //Deep sleep is in microseconds (1,000,000 (10^6) microseconds = 1 second)
}

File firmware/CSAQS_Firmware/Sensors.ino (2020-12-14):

void InitializeBME680()
{
  bme680Enabled = false;
  if(BME680.begin(I2C_STANDARD_MODE)) // Start BME680 using I2C, use first device found
  {
    if(DEBUG_OUT) Serial.println("BME680 initialized successfully, I2C address = 0x" + String(BME680.getI2CAddress(), HEX));  
    BME680.setOversampling(TemperatureSensor,Oversample16); // Use enumerated type values
    BME680.setOversampling(HumiditySensor,   Oversample8); // Use enumerated type values
    BME680.setOversampling(PressureSensor,   Oversample16); // Use enumerated type values
    BME680.setIIRFilter(IIR4); // Use enumerated type values
    BME680.setGas(320,150); //  for 150 milliseconds
    bme680Enabled = true;
  }
  else if(DEBUG_OUT) Serial.println("Unable to initialize BME 680.");
  delay(1000);
}


void InitialzieMAX30105()
{
  max30105Enabled = false;
  if(particleSensor.begin() == true)
  {    
    particleSensor.setup(); //Configure sensor. Use 6.4mA for LED drive
    if(DEBUG_OUT) Serial.println("MAX30105 initialized successfully. getRevisionID() = " + String(particleSensor.getRevisionID()) + ", getPartID() = " + String(particleSensor.readPartID()));
    max30105Enabled = true;
  }
  else if(DEBUG_OUT) Serial.println("Unable to initialize MAX30105.");
  delay(1000);
}


void InitializeNEOM8U()
{
  gpsEnabled = false;
  if(ubloxGPSObj.begin() == true) //Connect to the Ublox module using Wire port
  {
    delay(1000);
    ubloxGPSObj.setI2COutput(COM_TYPE_UBX); //Set the I2C port to output UBX only (turn off NMEA noise)
    if(DEBUG_OUT)
    {
      delay(1000);
      Serial.println("u-blox NEO-M8U initialzied successfully.  u-blox.IsConnected() = " + String(ubloxGPSObj.isConnected(100)));
      Serial.println("u-blox version = " + String(ubloxGPSObj.getProtocolVersionHigh()) + "." + String(ubloxGPSObj.getProtocolVersionLow()));
    }
    gpsEnabled = true;
  }
  else if(DEBUG_OUT) Serial.println("unable to initialize u-blox NEO-M8U.");
}


void PollPowerSupply()
{
  digitalWrite(MUX_SELECT, PWR_SUPPLY);
  delay(100);  //allow time for signal to settle
  read_A0 = SampleAnalogInput();
  vcc = ((float)read_A0 * (voltage_divider_scalar / ADC_resolution));
  if(DEBUG_OUT)
  {
    Serial.println("Power Supply A0 value: " + String(read_A0));
    Serial.println("Power Supply Voltage:  " + String(vcc));
  }
}


void PollNOxSensor()
{
  digitalWrite(MUX_SELECT, NOX_SENSOR);
  delay(100);  //allow time for signal to settle
  read_A0 = SampleAnalogInput();
  noxSensorRead = ((float)read_A0 * (NOx_voltage_divider_scalar / ADC_resolution));
  if(DEBUG_OUT)
  {
    Serial.println("NOx A0 value:       " + String(read_A0));
    Serial.println("NOx Sensor Voltage: " + String(noxSensorRead));
  }
}


void PollBME680()
{
  tempStr     = "";
  humidityStr = "";
  pressureStr = "";
  gasStr      = "";
  
  if(bme680Enabled)
  { 
    BME680.getSensorData(temp, humidity, pressure, gas);
    tempStr     = String(((float)temp)/100);
    humidityStr = String(((float)humidity)/1000);
    pressureStr = String(((float)pressure)/100);
    gasStr      = String((float)gas);
  }
  if(DEBUG_OUT)
  {
    Serial.println("temp:     " + tempStr);
    Serial.println("humidity: " + humidityStr);
    Serial.println("pressure: " + pressureStr);
    Serial.println("gas:      " + gasStr);
  }
}


void PollMAX30105()
{
  red   = "";
  green = "";
  IR    = "";
  if(max30105Enabled)
  {
    red   = String(particleSensor.getRed());
    green = String(particleSensor.getGreen());
    IR    = String(particleSensor.getIR());
  }
  if(DEBUG_OUT)
  {
     Serial.println("red:   " + red);
     Serial.println("green: " + green);
     Serial.println("IR:    " + IR);
  }
}


void PollNEOM8U()
{
  latitude  = "";
  longitude = "";
  altitude  = "";
  SIV = 0;
  if(gpsEnabled)
  {
    latitude  = String(ubloxGPSObj.getLatitude());
    delay(100);
    longitude = String(ubloxGPSObj.getLongitude());
    delay(100);
    altitude  = String(ubloxGPSObj.getAltitude());
    delay(100);
    SIV  = ubloxGPSObj.getSIV();
  }
  if(DEBUG_OUT)
  {
    Serial.println("latitude:  " + latitude);
    Serial.println("longitude: " + longitude);
    Serial.println("altitude:  " + altitude);
    Serial.println("SIV:       " + String(SIV));
  }
}

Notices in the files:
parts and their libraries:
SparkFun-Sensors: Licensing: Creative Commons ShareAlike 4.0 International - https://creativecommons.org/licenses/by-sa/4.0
